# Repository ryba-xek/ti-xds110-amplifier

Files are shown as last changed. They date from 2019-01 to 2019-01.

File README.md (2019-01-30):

# ti-xds110-amplifier
This is a signal amplifier board for TI XDS110 clones.

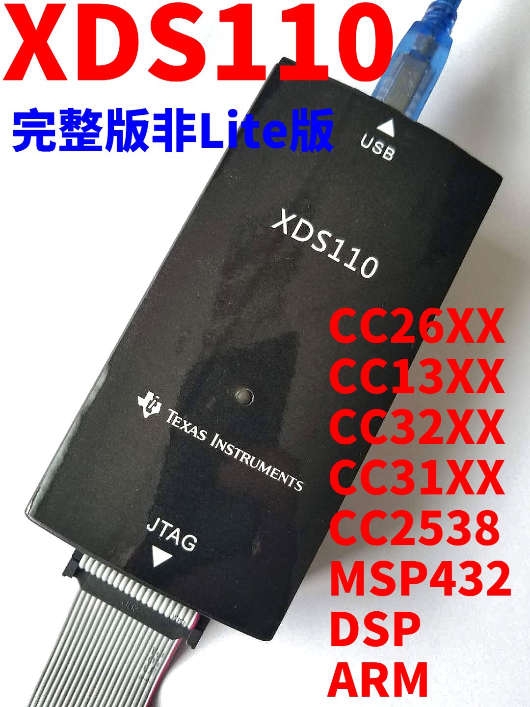
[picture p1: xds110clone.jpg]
Texas Instruments XDS110 clone

Bought xds110 clone that doesn't work with your board? Here's the solution.

The problem is the tm4c1294 chip can't provide enough power to produce a stable low signal.
This board uses a fast buffer IC to amplify the signal.

Tested at normal 2.5Mhz JTAG speed.

Works only with black xds110 clone, as it has 3.3V on pin 6 which breaks the standard.

http://processors.wiki.ti.com/images/9/90/Dbjtag_users_guide.pdf

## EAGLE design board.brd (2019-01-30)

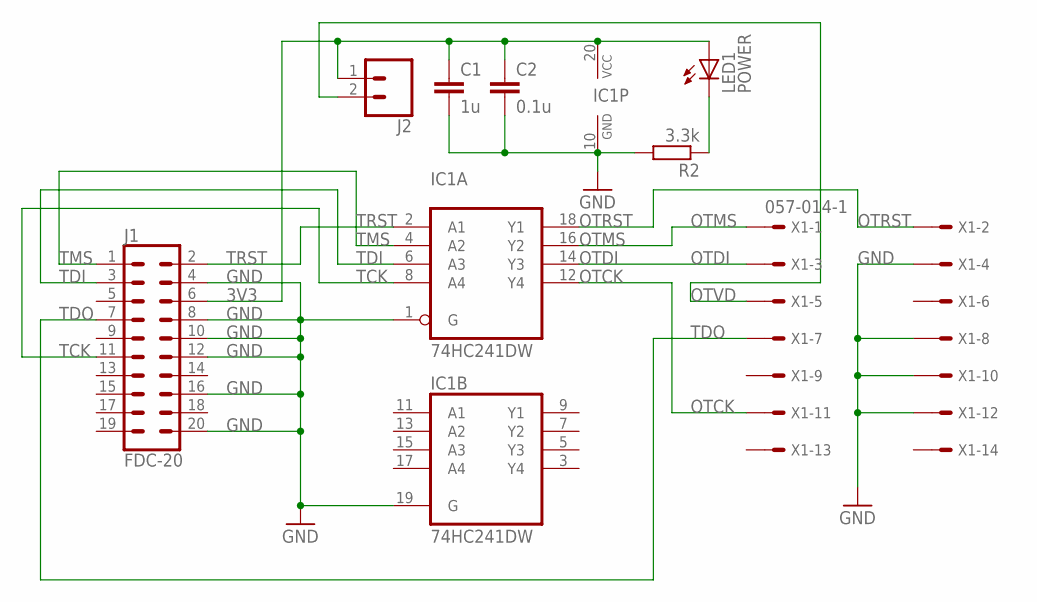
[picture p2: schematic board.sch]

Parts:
C1: 1u; C0805
C2: 0.1u; C0805
IC1: 74HC241DW; SO20W
J1: FDC-20; 2X10_NOSILK
J2: CONN_02; 1X02
LED1: POWER; CHIPLED_0805
R2: 3.3k; R0805
X1: 057-014-1

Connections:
3V3: C1.1, C2.1, IC1.20 (VCC), J1.6, J2.1, LED1.A
GND: C1.2, C2.2, IC1.1 (G), IC1.10 (GND), IC1.19 (G), J1.4, J1.8, J1.10, J1.12, J1.16, J1.20, R2.2, X1.4, X1.8, X1.10, X1.12
unnamed: LED1.C, R2.1
OTCK: IC1.12 (Y4), X1.11
OTDI: IC1.14 (Y3), X1.3
OTMS: IC1.16 (Y2), X1.1
OTRST: IC1.18 (Y1), X1.2
OTVD: J2.2, X1.5
TCK: IC1.8 (A4), J1.11
TDI: IC1.6 (A3), J1.3
TDO: J1.7, X1.7
TMS: IC1.4 (A2), J1.1
TRST: IC1.2 (A1), J1.2

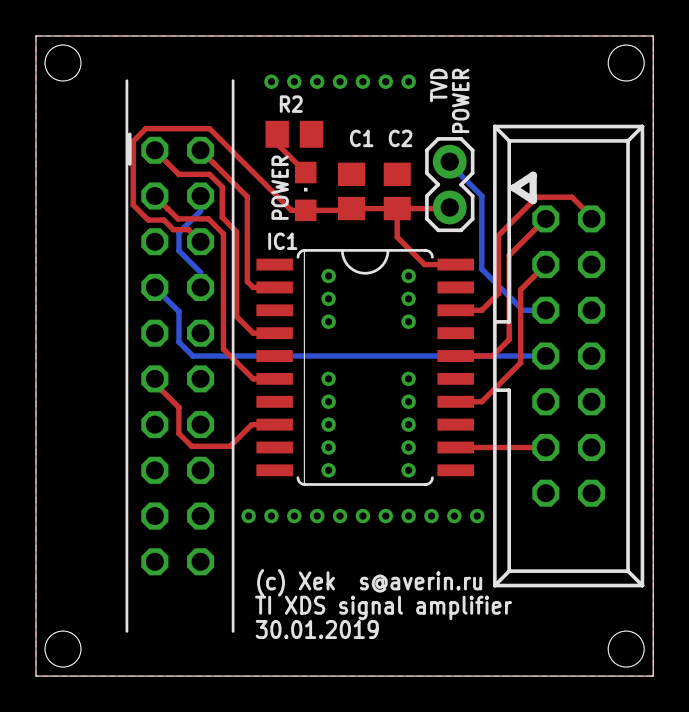
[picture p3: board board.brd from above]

Board: 2 copper layers, 34.3 x 35.6 mm, 8 parts (0 on the bottom side), 13 nets.

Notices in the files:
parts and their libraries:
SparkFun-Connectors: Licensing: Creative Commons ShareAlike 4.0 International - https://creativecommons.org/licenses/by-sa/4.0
